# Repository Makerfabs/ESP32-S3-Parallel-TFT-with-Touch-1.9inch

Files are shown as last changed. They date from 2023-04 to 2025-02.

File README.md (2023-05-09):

# ESP32-S3-Parallel-TFT-with-Touch-1.9inch

```
/* 
    Version:      V1.1
    Author:       Ricardo
    Create Date:  2023/4/27
*/
```

# Makerfabs

[Makerfabs home page](https://www.makerfabs.com/)

[Makerfabs Wiki](https://wiki.makerfabs.com/)

## Intruduce

Product Link:[ESP32-S3 Parallel TFT with Touch 1.9"](https://www.makerfabs.com/matouch-esp32-s3-parallel-tft-with-touch-1-9-inch.html?search=Esp32%20s3%201.9)

Wiki Link : [ESP32-S3 Parallel 1.9 TFT with Touch](https://wiki.makerfabs.com/ESP32_S3_Parallel_1.9_TFT_with_Touch.html)

IoT applications have a certain demand for the 1.9" screen. The small screen brings higher cost performance and utilization rate. Its main control chip adopts ESP32-S3R8 Dual-core LX7 microcontroller, it features Wifi/ WiFi& Bluetooth 5.0 + BT mesh.

At the same time, it supports battery and USB power supply methods, which brings many possibilities to its application. At the same time, it has a TF card, which can store and transfer sensor data. Also there 2 expansion connectors, with UART/ADC. The colorful display resolution is 320*170, with capacitive touch, which could be a proper solution for IoT applications.

## Features

- Controller: ESP32-S3
- Wireless: WiFi& Bluetooth 5.0
- LCD: 1.9", 320x170 resolution, driver ST7789V2
- LCD interface: 8 bit 8080
- Touch Panel Driver: CST816D
- USB: USB Native, Type-C
- Power Supply: USB Type-C 5.0V(4.0V~5.25V); 3.7V Lipo battery
- Button: Flash button and reset button
- Expansion interface: 2 (UART/ADC)
- MicroSD
- Arduino support
- MicroPython support: Yes
- Operation temperature: -40℃ to +85℃

## Usage

related library versions

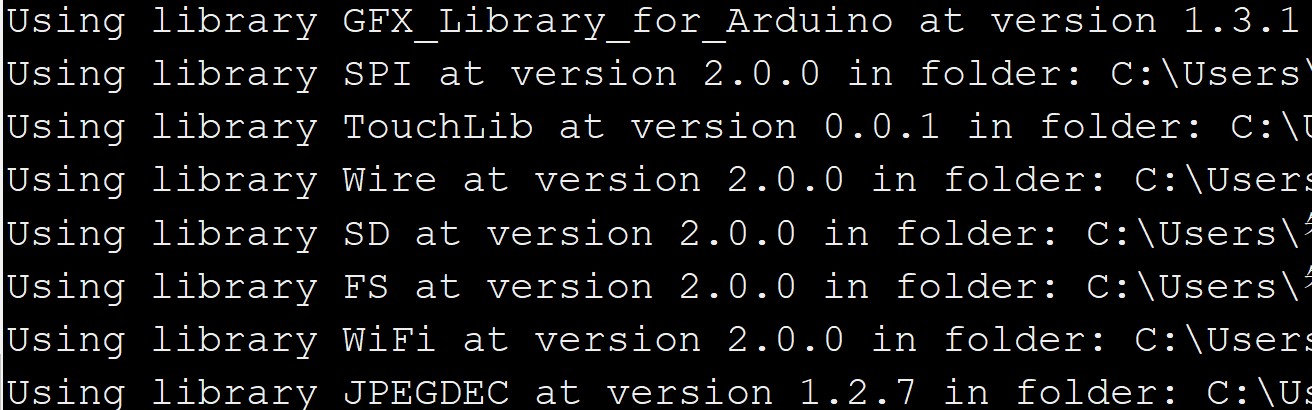
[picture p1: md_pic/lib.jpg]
library


- Use type-c use cable connect USB-TTL to PC.
- Select "ESP32-S3 DEV Module"
- Select PSRAM "OPI PSRAM"

"mf_Lvgl" library is modified from Lvgl library (version 8.3.2). 

Please unzip "lib/mf_Lvgl.zip"."TouchLib" and copy to arduino library directory.

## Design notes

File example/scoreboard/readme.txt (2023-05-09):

Unzip ui.zip.
And copy to arduino/library/

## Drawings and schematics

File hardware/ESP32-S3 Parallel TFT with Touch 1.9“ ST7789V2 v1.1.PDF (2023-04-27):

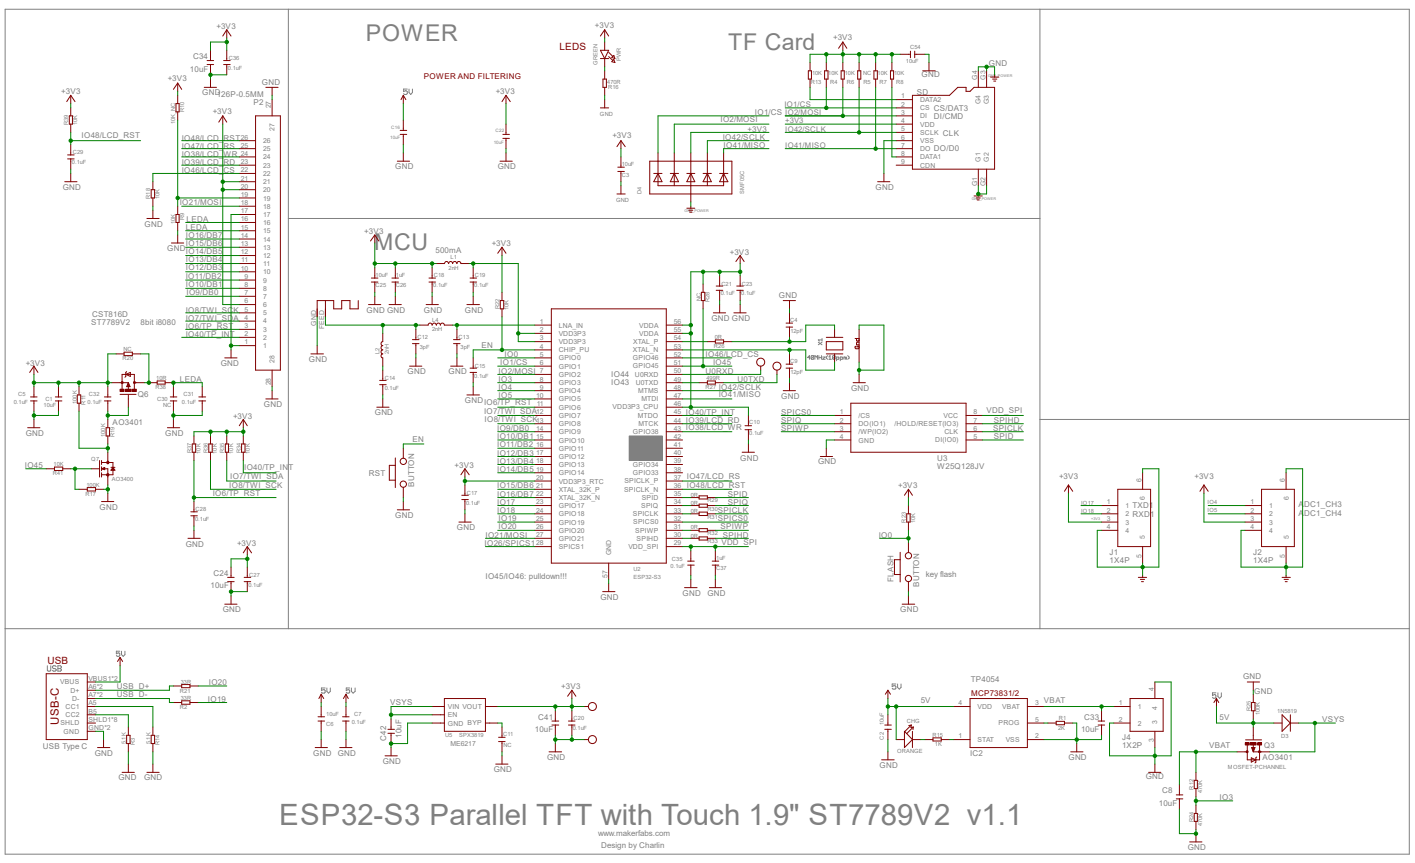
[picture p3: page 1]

IO38/LCD_WR
IO39/LCD_RD

key flash ESP32-S3 Parallel TFT with Touch 1.9" ST7789V2 v1.1

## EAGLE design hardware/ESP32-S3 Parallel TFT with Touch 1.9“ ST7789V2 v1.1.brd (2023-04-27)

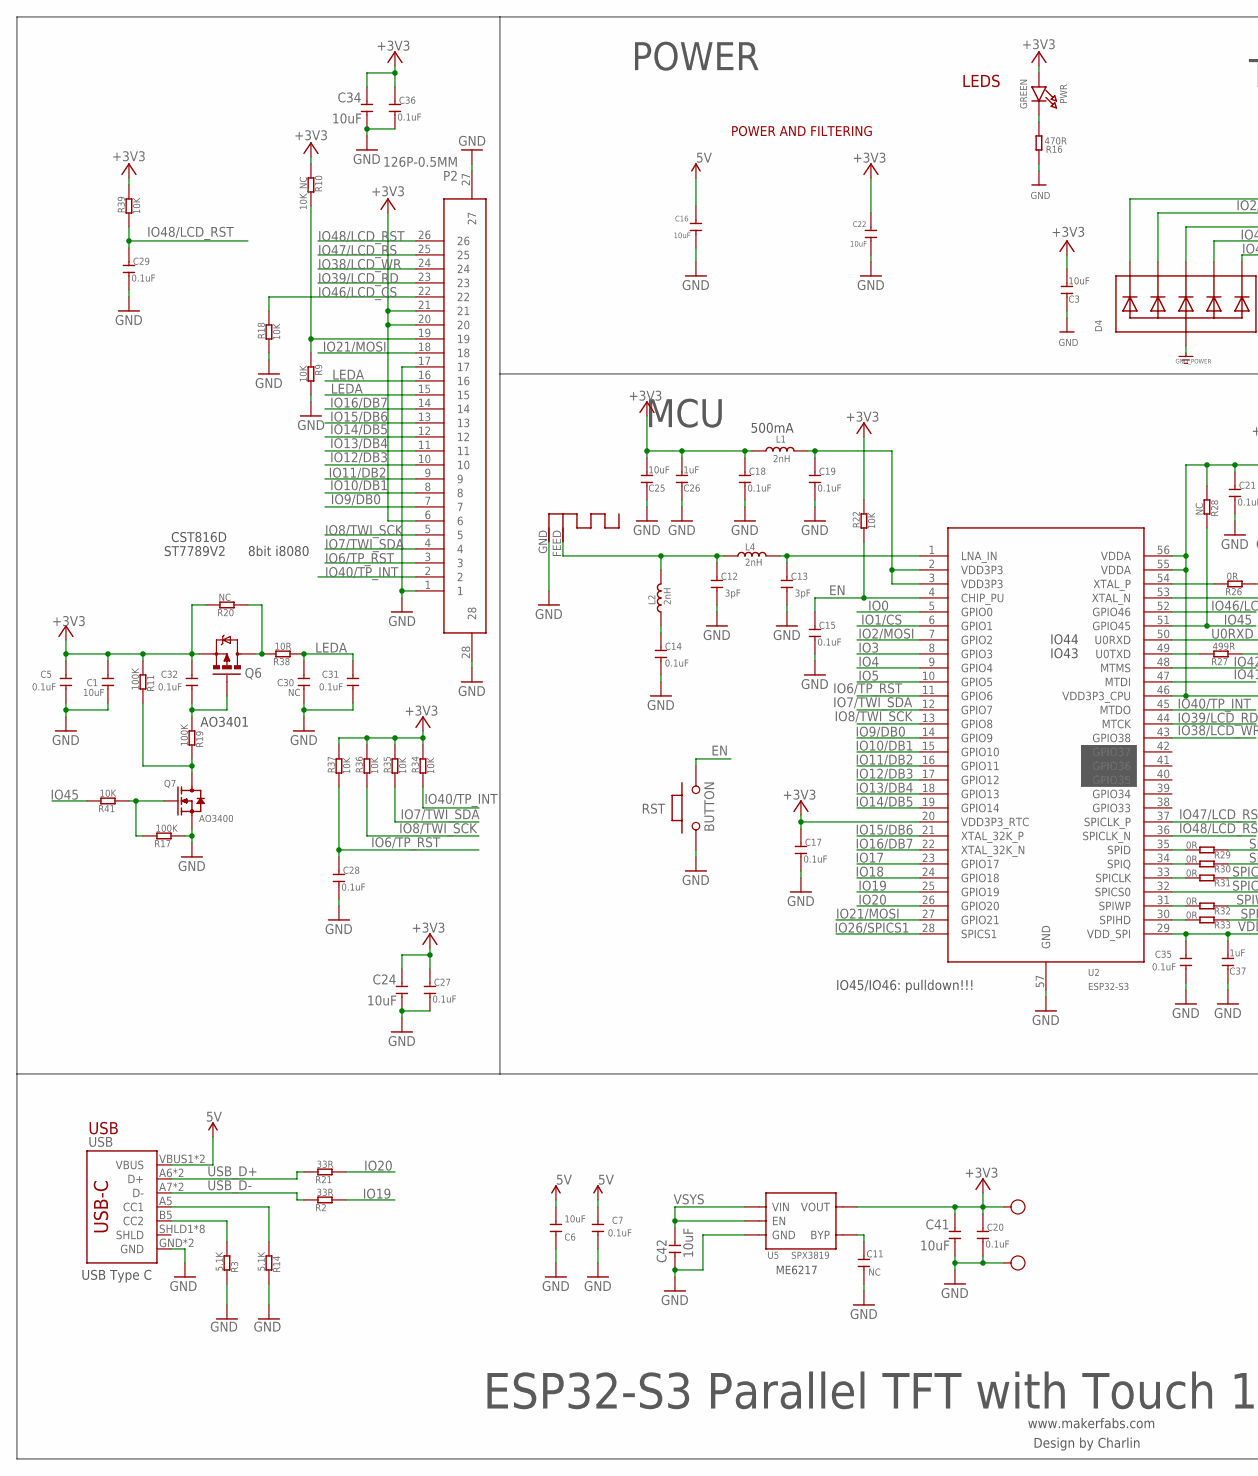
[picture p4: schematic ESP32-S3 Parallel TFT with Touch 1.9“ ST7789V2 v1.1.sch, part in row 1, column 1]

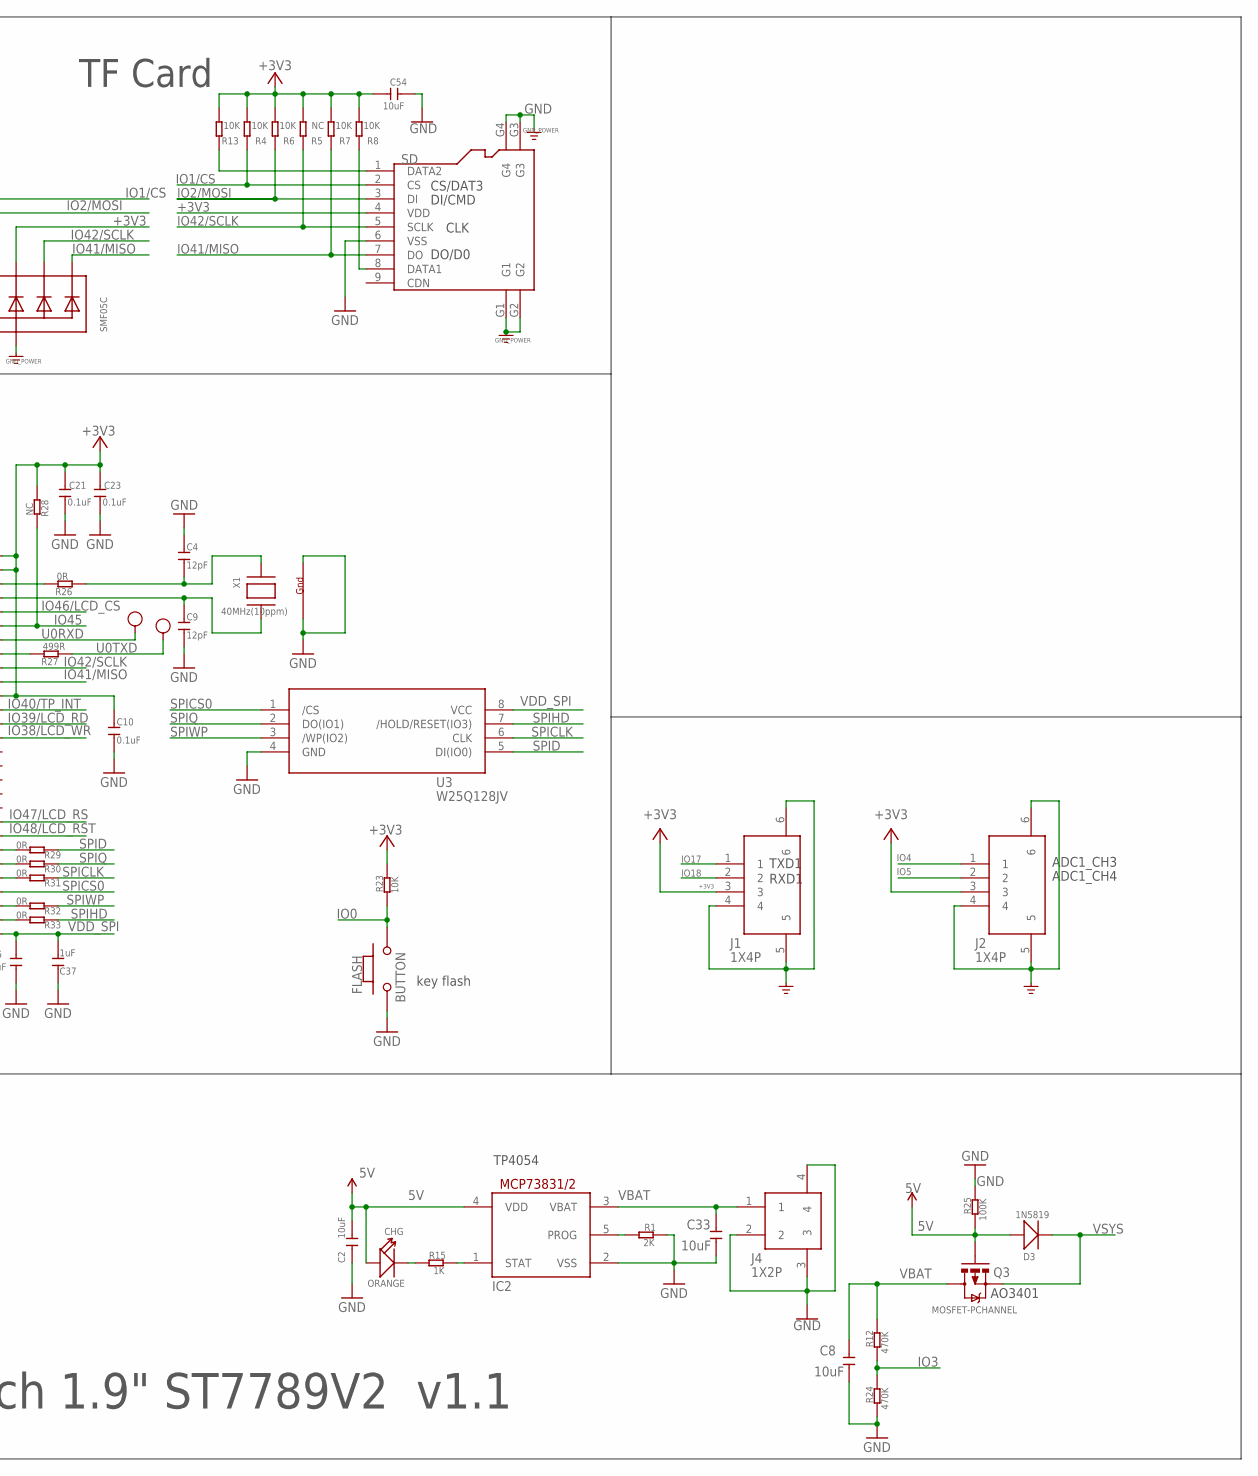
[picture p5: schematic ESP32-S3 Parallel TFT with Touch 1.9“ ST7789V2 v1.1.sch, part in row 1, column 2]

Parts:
ANT1: ANTENNA; RN-ANT
C1, C2, C8, C16, C22, C24, C33, C34, C41, C42: 10uF; 0603
C3, C6, C25, C54: 10uF; DISCRETE_C0603
C4, C9: 12pF; DISCRETE_C0402
C5, C7, C10, C14, C15, C17, C18, C19, C20, C21, C23, C27, C28, C29, C31, C32, C35, C36: 0.1uF; DISCRETE_C0402
C11: NC; DISCRETE_C0402
C12, C13: 3pF; DISCRETE_C0402
C26, C37: 1uF; DISCRETE_C0603
C30: NC; 0603
CHG: ORANGE; D0603
D3: 1N5819; SOD323
D4: SMF05C; SOT363
FLASH: BUTTON; 157SW
G: TEST-POINT'4545'; TP-D45MIL; PARTNO DNP
IC2: MCP73831/OT; SOT23-5L
J1, J2: 1X4P; 1X4P-SMT1.25MM
J4: 1X2P; 1X2P-SMT1.25MM
L1: 2nH; DISCRETE_L0603
L2, L4: 2nH; DISCRETE_L0402
P2: 126P-0.5MM; 1*26P-SMT0.5MM
PWR: GREEN; CHIPLED_0805_NOOUTLINE
Q3, Q6: MOSFET-PCHANNEL; SOT23-3
Q7: AO3400; DISCRETE_SOT23
R1: 2K; DISCRETE_R0402
R2, R21: 33R; DISCRETE_R0402
R3, R14: 5.1K; DISCRETE_R0402
R4, R6, R7, R8, R9, R13, R18, R22, R23, R34, R35, R36, R37, R39, R41: 10K; DISCRETE_R0402
R5, R20, R28: NC; DISCRETE_R0402
R10: 10K_NC; DISCRETE_R0402
R11, R17, R19, R25: 100K; DISCRETE_R0402
R12, R24: 470K; DISCRETE_R0402
R15: 1K; DISCRETE_R0402
R16: 470R; DISCRETE_R0402
R26, R29, R30, R31, R32, R33: 0R; DISCRETE_R0402
R27: 499R; DISCRETE_R0402
R38: 10R; DISCRETE_R0402
RST: BUTTON; 157SW
RX: TEST-POINT'4545'; TP-D45MIL; PARTNO DNP
SD: HOLDER-MICROSD-9P; 9P-SMD-W/-RING
TX: TEST-POINT'4545'; TP-D45MIL; PARTNO DNP
U2: ESP32-S3; QFN56-7*7MM
U3: W25Q128JV; SOIC-8-208MIL
U5: SPX3819; SOT23-5
USB: USB_C5; USB-C-16P-5
V: TEST-POINT'4545'; TP-D45MIL; PARTNO DNP
X1: 40MHz(10ppm); NX3225

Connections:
5V: C2.2, C6.2, C7.2, C16.1, CHG.+, D3.+, IC2.4 (VDD), Q3.1 (G), R25.1, USB.VBUS1 (VBUS), USB.VBUS2 (VBUS)
+3V3: C1.2, C3.2, C5.2, C10.2, C17.2, C18.2, C20.2, C21.2, C22.1, C23.2, C24.2, C25.2, C26.2, C27.2, C32.2, C34.2, C36.2, C41.2, C54.2, D4.4 (C3), J1.3, J2.3, L1.1, P2.6, P2.20, P2.21, PWR.A, Q6.2 (S), R4.2, R5.2, R6.2, R7.2, R8.2, R10.2, R11.1, R13.2, R20.2, R22.2, R23.2, R28.1, R34.2, R35.2, R36.2, R37.2, R39.2, SD.4 (VDD), U2.20 (VDD3P3_RTC), U2.46 (VDD3P3_CPU), U2.55 (VDDA), U2.56 (VDDA), U5.5 (VOUT), V.T
EN: C15.2, R22.1, RST.2, U2.4 (CHIP_PU)
GND: ANT1.GND, C1.1, C2.1, C3.1, C4.2, C5.1, C6.1, C7.1, C8.1, C9.1, C10.1, C11.1, C12.1, C13.1, C14.1, C15.1, C16.2, C17.1, C18.1, C19.1, C20.1, C21.1, C22.2, C23.1, C24.1, C25.1, C26.1, C27.1, C28.1, C29.1, C30.1, C31.1, C33.1, C34.1, C35.1, C36.1, C37.1, C41.1, C42.1, C54.1, D4.2 (A), FLASH.1, G.T, IC2.2 (VSS), J1.4, J1.5, J1.6, J2.4, J2.5, J2.6, J4.2, J4.3, J4.4, P2.1, P2.17, P2.27, P2.28, Q7.2 (S), R1.2, R3.2, R9.1, R14.2, R16.1, R17.1, R18.1, R24.1, R25.2, RST.1, SD.6 (VSS), SD.G1, SD.G2, SD.G3, SD.G4, U2.57 (GND), U3.4 (GND), U5.2 (GND), USB.GND, USB.GND2 (GND), X1.2 (G2), X1.4 (G1)
IO0: FLASH.2, R23.1, U2.5 (GPIO0)
IO1/CS: D4.1 (C1), R4.1, SD.2 (CS), U2.6 (GPIO1)
IO2/MOSI: D4.3 (C2), R6.1, SD.3 (DI), U2.7 (GPIO2)
IO3: R12.1, R24.2, U2.8 (GPIO3)
IO4: J2.1, U2.9 (GPIO4)
IO5: J2.2, U2.10 (GPIO5)
IO6/TP_RST: C28.2, P2.3, R37.1, U2.11 (GPIO6)
IO7/TWI_SDA: P2.4, R35.1, U2.12 (GPIO7)
IO8/TWI_SCK: P2.5, R36.1, U2.13 (GPIO8)
IO9/DB0: P2.7, U2.14 (GPIO9)
IO10/DB1: P2.8, U2.15 (GPIO10)
IO11/DB2: P2.9, U2.16 (GPIO11)
IO12/DB3: P2.10, U2.17 (GPIO12)
IO13/DB4: P2.11, U2.18 (GPIO13)
IO14/DB5: P2.12, U2.19 (GPIO14)
IO15/DB6: P2.13, U2.21 (XTAL_32K_P)
IO16/DB7: P2.14, U2.22 (XTAL_32K_N)
IO17: J1.1, U2.23 (GPIO17)
IO18: J1.2, U2.24 (GPIO18)
IO19: R2.1, U2.25 (GPIO19)
IO20: R21.1, U2.26 (GPIO20)
IO21/MOSI: P2.18, U2.27 (GPIO21)
IO26/SPICS1: U2.28 (SPICS1)
IO38/LCD_WR: P2.24, U2.43 (GPIO38)
IO39/LCD_RD: P2.23, U2.44 (MTCK)
IO40/TP_INT: P2.2, R34.1, U2.45 (MTDO)
IO41/MISO: D4.6 (C5), R7.1, SD.7 (DO), U2.47 (MTDI)
IO42/SCLK: D4.5 (C4), R5.1, SD.5 (SCLK), U2.48 (MTMS)
IO45: R28.2, R41.2, U2.51 (GPIO45)
IO46/LCD_CS: P2.22, R18.2, U2.52 (GPIO46)
IO47/LCD_RS: P2.25, U2.37 (SPICLK_P)
IO48/LCD_RST: C29.2, P2.26, R39.1, U2.36 (SPICLK_N)
LEDA: C30.2, C31.2, P2.15, P2.16, R38.1
unnamed: IC2.5 (PROG), R1.1
unnamed: C32.1, Q6.1 (G), R19.1
unnamed: R14.1, USB.A5 (CC1)
unnamed: PWR.C, R16.2
unnamed: P2.19, R9.2, R10.1
unnamed: Q6.3 (D), R20.1, R38.2
unnamed: R3.1, USB.B5 (CC2)
unnamed: Q7.3 (D), R11.2, R19.2
unnamed: Q7.1 (G), R17.2, R41.1
unnamed: CHG.-, R15.1
unnamed: IC2.1 (STAT), R15.2
unnamed: ANT1.FEED, C12.2, L2.2, L4.1
unnamed: C13.2, L4.2, U2.1 (LNA_IN)
unnamed: R29.2, U2.35 (SPID)
unnamed: C19.2, L1.2, U2.2 (VDD3P3), U2.3 (VDD3P3)
unnamed: C14.2, L2.1
unnamed: R30.2, U2.34 (SPIQ)
unnamed: R26.2, U2.54 (XTAL_P)
unnamed: R31.2, U2.33 (SPICLK)
unnamed: R32.2, U2.31 (SPIWP)
unnamed: R33.2, U2.30 (SPIHD)
unnamed: R13.1, SD.1 (DATA2)
unnamed: R8.1, SD.8 (DATA1)
unnamed: R27.2, U2.49 (U0TXD)
unnamed: C9.2, U2.53 (XTAL_N), X1.3 (X2)
unnamed: C4.1, R26.1, X1.1 (X1)
unnamed: C11.2, U5.4 (BYP)
SPICLK: R31.1, U3.6 (CLK)
SPICS0: U2.32 (SPICS0), U3.1 (/CS)
SPID: R29.1, U3.5 (DI(IO0))
SPIHD: R33.1, U3.7 (/HOLD/RESET(IO3))
SPIQ: R30.1, U3.2 (DO(IO1))
SPIWP: R32.1, U3.3 (/WP(IO2))
U0RXD: RX.T, U2.50 (U0RXD)
U0TXD: R27.1, TX.T
USB_D+: R21.2, USB.A6 (D+), USB.B6 (D+)
USB_D-: R2.2, USB.A7 (D-), USB.B7 (D-)
VBAT: C8.2, C33.2, IC2.3 (VBAT), J4.1, Q3.3 (D), R12.2
VDD_SPI: C35.2, C37.2, U2.29 (VDD_SPI), U3.8 (VCC)
VSYS: C42.2, D3.-, Q3.2 (S), U5.1 (VIN), U5.3 (EN)

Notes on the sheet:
www.makerfabs.com
Design by Charlin
LEDS
POWER AND FILTERING
key flash
ESP32-S3 Parallel TFT with Touch 1.9" ST7789V2 v1.1
POWER
TF Card
USB
USB Type C
MCU
500mA
ME6217
ADC1_CH3
ADC1_CH4
TP4054
AO3401
TXD1
RXD1
8bit i8080
IO45/IO46: pulldown!!!
IO43
IO44
CST816D
ST7789V2
CS/DAT3
DI/CMD
DO/D0
CLK

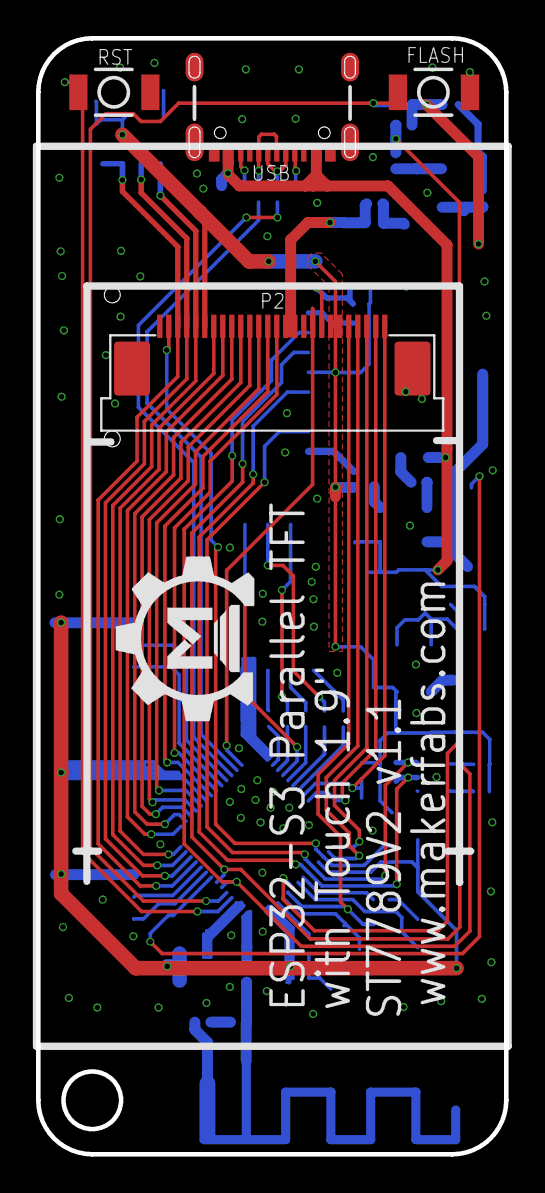
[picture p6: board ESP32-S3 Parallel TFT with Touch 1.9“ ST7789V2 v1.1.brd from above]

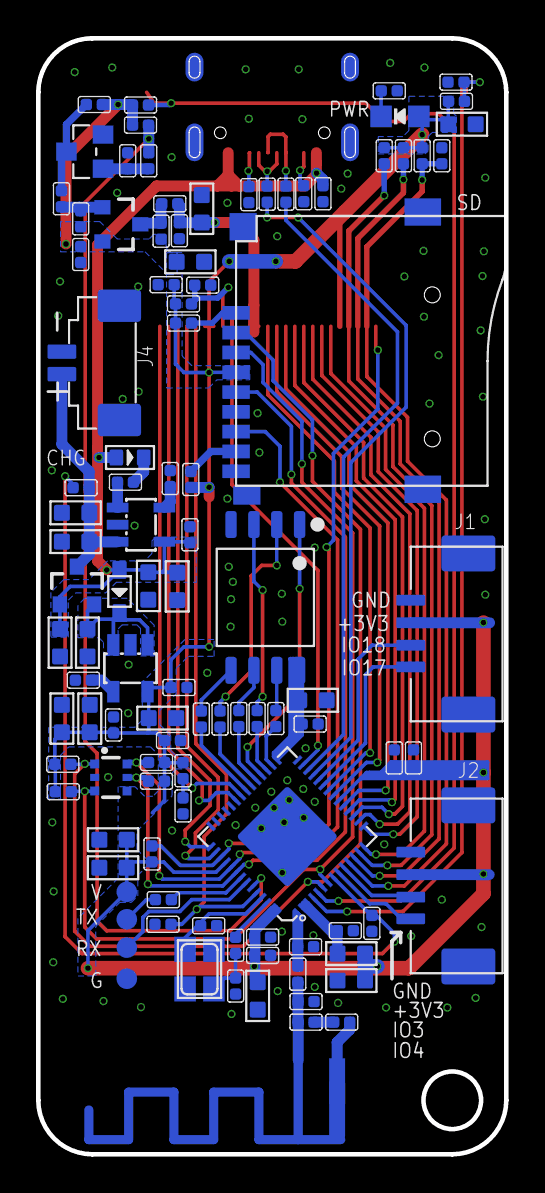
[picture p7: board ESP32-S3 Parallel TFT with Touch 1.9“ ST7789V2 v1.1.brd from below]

Board: 2 copper layers, 26.0 x 62.0 mm, 109 parts (104 on the bottom side), 76 nets.

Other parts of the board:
U$1: MAKERFABS_0.3

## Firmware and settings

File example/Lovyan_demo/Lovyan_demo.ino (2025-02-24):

/*
ESP32-S3 Parallel 1.9" TFT with Touch

Library version:
Arduino IDE V2.3.4
esp32 V2.0.16
LovyanGFX V0.4.18

Tools:
Flash size: 16MB(128Mb)
Partition Schrme: 16M Flash(3MB APP/9.9MB FATFS)
PSRAM: OPI PSRAM
*/

#define LGFX_USE_V1
#include <LovyanGFX.hpp>

class LGFX : public lgfx::LGFX_Device
{
lgfx::Panel_ST7789      _panel_instance;
lgfx::Bus_Parallel8 _bus_instance;   // 8ビットパラレルバスのインスタンス (ESP32のみ)
lgfx::Light_PWM     _light_instance;

public:

  LGFX(void)
  {
    { // バス制御の設定を行います。
      auto cfg = _bus_instance.config();    // バス設定用の構造体を取得します。

// 8ビットパラレルバスの設定
      //cfg.i2s_port = I2S_NUM_1;     // 使用するI2Sポートを選択 (I2S_NUM_0 or I2S_NUM_1) (ESP32のI2S LCDモードを使用します)
      cfg.freq_write = 20000000;    // 送信クロック (最大20MHz, 80MHzを整数で割った値に丸められます)
      cfg.pin_wr =  38;              // WR を接続しているピン番号
      cfg.pin_rd =  39;              // RD を接続しているピン番号
      cfg.pin_rs = 47;              // RS(D/C)を接続しているピン番号
      cfg.pin_d0 = 9;              // D0を接続しているピン番号
      cfg.pin_d1 = 10;              // D1を接続しているピン番号
      cfg.pin_d2 = 11;              // D2を接続しているピン番号
      cfg.pin_d3 = 12;              // D3を接続しているピン番号
      cfg.pin_d4 = 13;              // D4を接続しているピン番号
      cfg.pin_d5 = 14;              // D5を接続しているピン番号
      cfg.pin_d6 = 15;              // D6を接続しているピン番号
      cfg.pin_d7 = 16;              // D7を接続しているピン番号
//

      _bus_instance.config(cfg);    // 設定値をバスに反映します。
      _panel_instance.setBus(&_bus_instance);      // バスをパネルにセットします。
    }

    { // 表示パネル制御の設定を行います。
      auto cfg = _panel_instance.config();    // 表示パネル設定用の構造体を取得します。

      cfg.pin_cs           =    46;  // CSが接続されているピン番号   (-1 = disable)
      cfg.pin_rst          =    1;  // RSTが接続されているピン番号  (-1 = disable)
      cfg.pin_busy         =    -1;  // BUSYが接続されているピン番号 (-1 = disable)

      // ※ 以下の設定値はパネル毎に一般的な初期値が設定されていますので、不明な項目はコメントアウトして試してみてください。

      cfg.panel_width      =   170;  // 実際に表示可能な幅
      cfg.panel_height     =   320;  // 実際に表示可能な高さ
      cfg.offset_x         =    35;  // パネルのX方向オフセット量
      cfg.offset_y         =     0;  // パネルのY方向オフセット量
      cfg.offset_rotation  =     0;  // 回転方向の値のオフセット 0~7 (4~7は上下反転)
      cfg.dummy_read_pixel =     8;  // ピクセル読出し前のダミーリードのビット数
      cfg.dummy_read_bits  =     1;  // ピクセル以外のデータ読出し前のダミーリードのビット数
      cfg.readable         =  true;  // データ読出しが可能な場合 trueに設定
      cfg.invert           = true;  // パネルの明暗が反転してしまう場合 trueに設定
      cfg.rgb_order        = false;  // パネルの赤と青が入れ替わってしまう場合 trueに設定
      cfg.dlen_16bit       = false;  // 16bitパラレルやSPIでデータ長を16bit単位で送信するパネルの場合 trueに設定
      cfg.bus_shared       =  false;  // SDカードとバスを共有している場合 trueに設定(drawJpgFile等でバス制御を行います)

      _panel_instance.config(cfg);
    }

//*
    { // バックライト制御の設定を行います。（必要なければ削除）
      auto cfg = _light_instance.config();    // バックライト設定用の構造体を取得します。

      cfg.pin_bl = 45;              // バックライトが接続されているピン番号
      cfg.invert = false;           // バックライトの輝度を反転させる場合 true
      cfg.freq   = 44100;           // バックライトのPWM周波数
      cfg.pwm_channel = 7;          // 使用するPWMのチャンネル番号

      _light_instance.config(cfg);
      _panel_instance.setLight(&_light_instance);  // バックライトをパネルにセットします。
    }
    setPanel(&_panel_instance); // 使用するパネルをセットします。
  }
};

// 準備したクラスのインスタンスを作成します。
LGFX display;

void setup(void)
{
  // SPIバスとパネルの初期化を実行すると使用可能になります。
  display.init();
  display.fillScreen(TFT_RED);
  delay(1000);
  display.fillScreen(TFT_GREEN);
  delay(1000);
  display.fillScreen(TFT_BLUE);
  delay(1000);
  display.fillScreen(TFT_BLACK);
  delay(1000);
  display.fillScreen(TFT_WHITE);
}


void loop(void)
{
}

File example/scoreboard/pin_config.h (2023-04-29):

#define WIFI_SSID "Makerfabs"
#define WIFI_PASSWORLD "20160704"

#define PIN_LCD_BL 45

#define PIN_LCD_D0 9
#define PIN_LCD_D1 10
#define PIN_LCD_D2 11
#define PIN_LCD_D3 12
#define PIN_LCD_D4 13
#define PIN_LCD_D5 14
#define PIN_LCD_D6 15
#define PIN_LCD_D7 16

#define PIN_LCD_RST 48
#define PIN_LCD_CS 46
#define PIN_LCD_DC 47 // RS
#define PIN_LCD_WR 38
#define PIN_LCD_RD 39

#define PIN_BUTTON_1 0
#define PIN_BUTTON_2 -1 // 14
#define PIN_BAT_VOLT 3

#define PIN_IIC_SCL 8
#define PIN_IIC_SDA 7

#define PIN_TOUCH_INT 40
#define PIN_TOUCH_RES 6

#define SD_SCK 42
#define SD_MISO 41
#define SD_MOSI 2
#define SD_CS 1

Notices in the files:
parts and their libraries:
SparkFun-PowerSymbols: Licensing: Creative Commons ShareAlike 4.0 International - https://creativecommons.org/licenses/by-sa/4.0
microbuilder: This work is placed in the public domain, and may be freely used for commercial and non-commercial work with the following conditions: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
